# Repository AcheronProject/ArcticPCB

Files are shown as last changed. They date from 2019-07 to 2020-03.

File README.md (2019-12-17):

# Acheron 60-SM-S-STM32-MX-TH-WI (Codename "ArcticPCB")

Acheron Logo

See [this page](https://gondolindrim.github.io/AcheronDocs/arctic/intro.html) for the ArcticPCB documentation.

## Introduction

Arctic is an STM32F072-based universal 60% keyboard PCB featuring limited layouts and features. The layouts were cherry-picked by enthusiast ArcticFox and consist of only Tsangan bottom row. 

This PCB also features "relief" flex cuts aimed at improving keyboard typing feeling.

Arctic hold a very special place in my heart as it was one of the first two PCBs, together with the KeebsPCB, in the Acheron Project and effectively inaugurated it.

## Contributors

- Raphael "ArcticFox" Hochheim for helping choosing the compatible layouts
- Felipe 'MrKeebs" Coury who paid for the V1 prototypes and helped immensely by funcing my learning
- PCBWay for sponsoring the pre-revision Alpha prototypes

## Supported layouts

Click [this link](http://www.keyboard-layout-editor.com/#/gists/73be427d3e8086a9253feece2dae6974) for the KLE file for the Arctic.

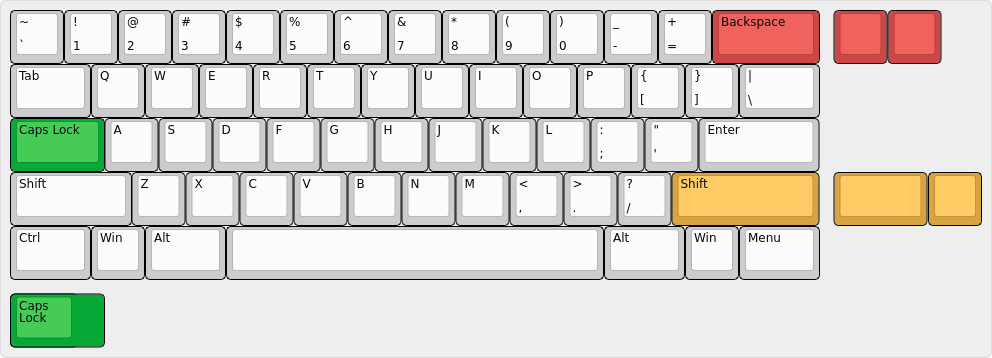
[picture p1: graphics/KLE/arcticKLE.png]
Arctic layouts


## Renders

Click at the images to zoom in.

Renders generated by the [tracespace.io](https://tracespace.io/view/) site.

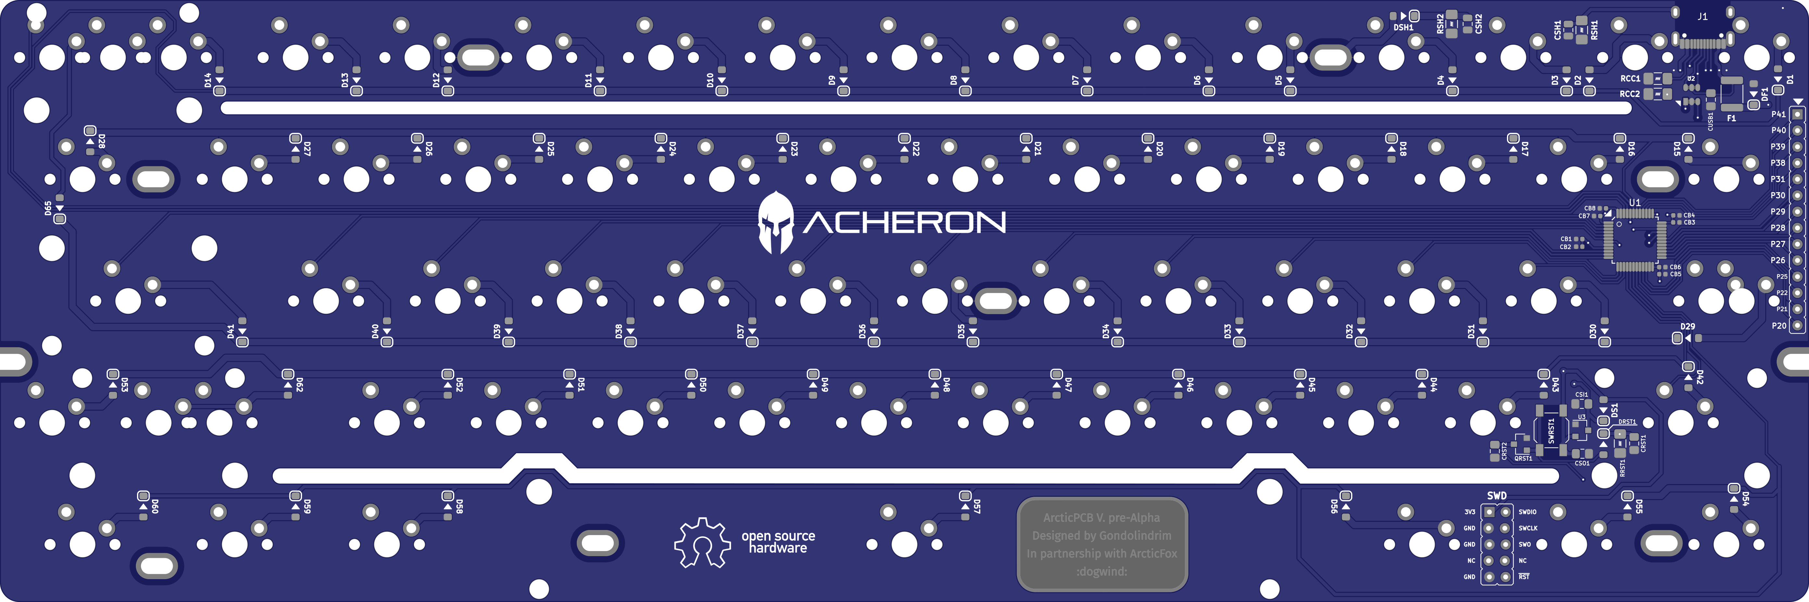
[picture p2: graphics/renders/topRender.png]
ArcticPCB Top Render


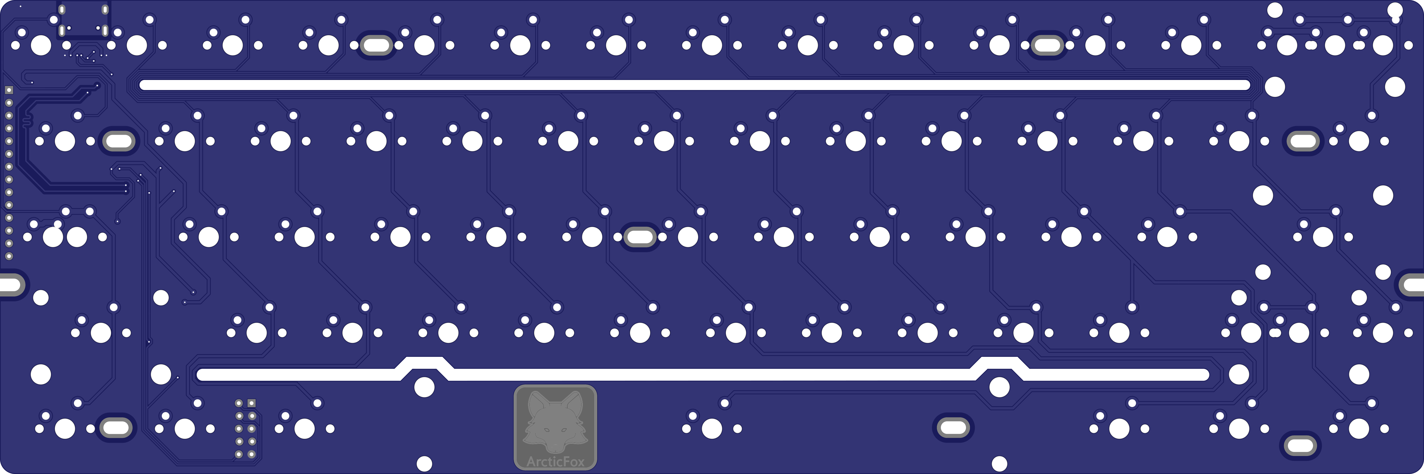
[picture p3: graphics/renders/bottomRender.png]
ArcticPCB Bottom Render


## PCBWay sponsorship

The pre-revision Alpha of the ArcticPCB was sponsored by [PCBWay](http://www.pcbway.com), a big asian PCB manufacturer that provided prototypes for the Arctic.

The review article can be found at [the AcheronDocs page](https://gondolindrim.github.io/AcheronDocs/pcbway/sponsorship.html).

## Icon

The Fox icon was based on [this design](https://www.flaticon.com/free-icon/fox_112476) and slightly modified.

## Copyright notice

This project is released under the Acheron Open-Hardware License V1.2. For the license, please refer to the LICENCE.md file.

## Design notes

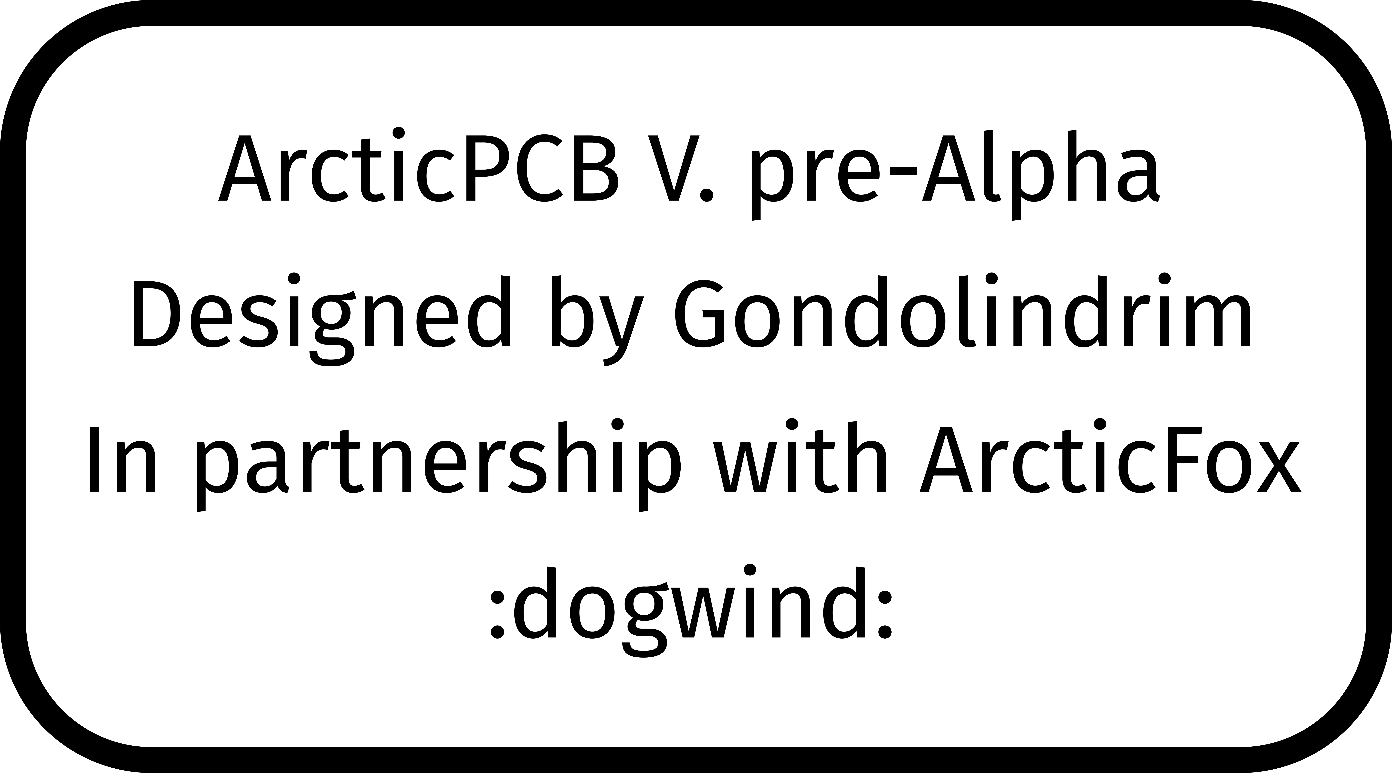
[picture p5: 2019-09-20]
graphics/arcticLabel/arcticLabel.png

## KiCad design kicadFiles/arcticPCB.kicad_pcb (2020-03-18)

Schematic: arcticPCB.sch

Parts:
CB1: 1uF; C_0402_1005Metric
CB2: 10n; C_0402_1005Metric
CB3, CB5, CB8: 100n; C_0402_1005Metric
CB4, CB6: 4.7uF; C_0402_1005Metric
CB7: 100nF; C_0402_1005Metric
CRST1: 10u; C_0805_2012Metric_Pad1.15x1.40mm_HandSolder
CRST2: 4.7n; C_0805_2012Metric_Pad1.15x1.40mm_HandSolder
CSH1, CSH2: 4.7nF; C_0805_2012Metric
CSI1: 100n; C_0805_2012Metric_Pad1.15x1.40mm_HandSolder
CSO1: 100n; C_0805_2012Metric_Pad1.15x1.40mm_HandSolder
CUSB1: 100n; C_0805_2012Metric_Pad1.15x1.40mm_HandSolder
D1, D2, D3, D4, D5, D6, D7, D8, D9, D10, D11, D12, D13, D14, D15, D16, D17, D18, D19, D20, D21, D22, D23, D24, D25, D26, D27, D28, D29, D30, D31, D32, D33, D34, D35, D36, D37, D38, D39, D40, D41, D42, D43, D44, D45, D46, D47, D48, D49, D50, D51, D52, D53, D54, D55, D56, D57, D58, D59, D60, D62, D65: 1N4148; D_SOD-123
DF1: RB060M-60TR; D_SOD-123
DRST1: 1N4148; D_SOD-123
DS1: 1N4148; D_SOD-123
DSH1: 1N4007; D_SOD-123
F1: Polyfuse; Fuse_1812_4532
H1, H6: Half Side Hole; halfSideHole
H2: Mounting Hole; MoutingHole_Oval_7mm_5.0x2.5mm
H3, H4, H5, H7, H8, H9, H10: Oval Mounting Hole; MoutingHole_Oval_7mm_5.0x2.5mm
J1: TYPE-C-31-M12_13; TYPE-C-31-M-12
J2: Conn_01x14; PinHeader_1x14_P2.54mm_Vertical
J3: Conn_ARM_JTAG_SWD_10
L1: ArcticLogo; arcticLogoFilled
L2: OSHLogo; osh-logo
L3: Acheron Logo; acheronLong
L4: ArcticLabel; arcticLabel
L5: Acheron Logo; arcticLabelMask
QRST1: DTC123J; SOT-23
RCC1, RCC2: 5.1k; R_SMD_1026
RRST1: 100k; R_SMD_1026
RSH1, RSH2: 1M; R_SMD_1026
SW1: ESC; MX100
SW2: 1; MX100
SW3: 2; MX100
SW4: 3; MX100
SW5: 4; MX100
SW6: 5; MX100
SW7: 6; MX100
SW8: 7; MX100
SW9: 8; MX100
SW10: 9; MX100
SW11: 0; MX100
SW12: -_; MX100
SW13: +=; MX100
SW14: 2U BKSP; MX200
SW15: TAB_150; MX150
SW16: Q; MX100
SW17: W; MX100
SW18: E; MX100
SW19: R; MX100
SW20: T; MX100
SW21: Y; MX100
SW22: U; MX100
SW23: I; MX100
SW24: O; MX100
SW25: P; MX100
SW26: [{; MX100
SW27: ]}; MX100
SW28: \\|_150; MX150
SW29: CAPS_175; MX175
SW30: A; MX100
SW31: S; MX100
SW32: D; MX100
SW33: F; MX100
SW34: G; MX100
SW35: H; MX100
SW36: J; MX100
SW37: K; MX100
SW38: L; MX100
SW39: :;; MX100
SW40: \"'; MX100
SW41: ENTER_225; MX225R
SW42: LSHIFT_225; MX225
SW43: Z; MX100
SW44: X; MX100
SW45: C; MX100
SW46: V; MX100
SW47: B; MX100
SW48: N; MX100
SW49: M; MX100
SW50: <,; MX100
SW51: >.; MX100
SW52: ?/; MX100
SW53: RSHIFT_275; MX275
SW54: LCTRL_150; MX150
SW55: LGUI_100; MX100
SW56: LALT_150; MX150
SW57: SPACE_7U; MX700R
SW58: RALT_150; MX150
SW59: RGUI_100; MX100
SW60: RCTRL_150; MX150
SW61: FN_100; MX100
SW62: RSHIFT_175; MX175
SW63: STEPPED_CAPS_125; MX125
SW64: 1U LBKSP; MX100
SW65: 1U RBKSP; MX100
SWRST1: SW_Push; smdPushBtn
U1: STM32F072-LQFP48; LQFP-48_7x7mm_P0.5mm
U2: USBLC6-2SC6; SOT-23-6
U3: MCP1700-3302E_SOT23; SOT-23

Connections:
3.3V: CB1.2, CB2.2, CB3.2, CB4.2, CB5.2, CB6.2, CB7.1, CB8.2, CSO1.2, DS1.2 (A), J3.1 (VTref), SWRST1.1, U1.1 (VBAT), U1.9 (VDDA), U1.24 (VDD), U1.36 (VDDIO2), U1.48 (VDD), U3.2 (VO)
5V: CSI1.2, DF1.1 (K), DS1.1 (K), F1.1, U3.3 (VI)
/SHIELD: CSH1.2, J1.S (SHIELD), RSH1.1
BOOT0: CRST1.2, DRST1.1 (K), RRST1.1, U1.44 (BOOT0)
CASE: DSH1.2 (A), H8.1
Col1: SW1.1 (Col), SW15.1 (Col), SW29.1 (Col), SW42.1 (Col), SW54.1 (Col), SW63.1 (Col), U1.18 (PB0/TIM3_CH3/ADC_IN8)
Col2: SW2.1 (Col), SW16.1 (Col), SW30.1 (Col), SW43.1 (Col), SW55.1 (Col), U1.15 (PA5/ADC_IN5/DAC_OUT2)
Col3: SW3.1 (Col), SW17.1 (Col), SW31.1 (Col), SW44.1 (Col), SW56.1 (Col), U1.14 (PA4/TIM14_CH1/ADC_IN4)
Col4: SW4.1 (Col), SW18.1 (Col), SW32.1 (Col), SW45.1 (Col), U1.13 (PA3/TIM15_CH2/ADC_IN3)
Col5: SW5.1 (Col), SW19.1 (Col), SW33.1 (Col), SW46.1 (Col), U1.12 (PA2/ADC_IN2)
Col6: SW6.1 (Col), SW20.1 (Col), SW34.1 (Col), SW47.1 (Col), U1.11 (PA1/ADC_IN1)
Col7: SW7.1 (Col), SW21.1 (Col), SW35.1 (Col), SW48.1 (Col), SW57.1 (Col), U1.10 (PA0/ADC_IN0)
Col8: SW8.1 (Col), SW22.1 (Col), SW36.1 (Col), SW49.1 (Col), U1.6 (PF1/OSC_OUT)
Col9: SW9.1 (Col), SW23.1 (Col), SW37.1 (Col), SW50.1 (Col), U1.5 (PF0/OSC_IN)
Col10: SW10.1 (Col), SW24.1 (Col), SW38.1 (Col), SW51.1 (Col), SW58.1 (Col), U1.4 (PC15/OSC32_OUT)
Col11: SW11.1 (Col), SW25.1 (Col), SW39.1 (Col), SW52.1 (Col), SW59.1 (Col), U1.3 (PC14/OSC32_IN)
Col12: SW12.1 (Col), SW26.1 (Col), SW40.1 (Col), SW53.1 (Col), SW60.1 (Col), SW62.1 (Col), U1.2 (PC13)
Col13: SW13.1 (Col), SW27.1 (Col), SW41.1 (Col), SW61.1 (Col), U1.46 (SPI2_NSS/I2S2_WS/I2C1_SDA/TIM17_CH1/PB9)
Col14: SW14.1 (Col), SW28.1 (Col), SW64.1 (Col), SW65.1 (Col), U1.45 (I2C1_SCL/TIM16_CH1/PB8)
D+: U1.33 (USB_DP/PA12), U2.3 (IO2)
D-: U1.32 (USB_DM/TIM1_CH4/PA11), U2.1 (IO1)
DBus+: J1.A6 (D+), J1.B6 (D+), U2.4 (IO2)
DBus-: J1.A7 (D-), J1.B7 (D-), U2.6 (IO1)
Extra1: J2.1, U1.41 (SPI1_MOSI/I2S1_SD/TIM3_CH2/PB5)
Extra2: J2.2, U1.40 (SPI1_MISO/I2S1_MCK/TIM3_CH1/PB4)
Extra3: J2.3, U1.39 (SPI1_SCK/I2S1_CK/TIM2_CH2/PB3)
Extra4: J2.4, U1.38 (PA2)
Extra5: J2.5, U1.31 (TIM1_CH3/PA10)
Extra6: J2.6, U1.30 (TIM1_CH2/PA9)
Extra7: J2.7, U1.29 (TIM1_CH1/PA8)
Extra8: J2.8, U1.28 (SPI2_MOSI/I2S2_SD/PB15)
Extra9: J2.9, U1.27 (PB14/SPI2_MISO/I2S2_MCK/I2C2_SDA/TIM15_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)
Extra10: J2.10, U1.26 (SPI2_SCK/I2S2_CK/I2C2_SCL/PB13)
Extra11: J2.11, U1.25 (PB12)
Extra12: J2.12, U1.22 (PB11/TIM2_CH4/I2C2_SDA)
Extra13: J2.13, U1.21 (PB10/SPI2_SCK/I2C2_SCL/TIM2_CH3)
Extra14: J2.14, U1.20 (PB2)
GND: CB1.1, CB2.1, CB3.1, CB4.1, CB5.1, CB6.1, CB7.2, CB8.1, CRST1.1, CRST2.2, CSH1.1, CSH2.1, CSI1.1, CSO1.1, CUSB1.1, DF1.2 (A), J1.A1 (GND), J1.B1 (GND), J3.3 (GND), J3.5 (GND), J3.9 (GNDDetect), QRST1.2 (E), RCC1.1, RCC2.1, RRST1.2, RSH1.2, RSH2.2, U1.8 (VSSA), U1.23 (VSS), U1.35 (VSS), U1.47 (VSS), U2.2 (GND), U3.1 (GND)
NRST: CRST2.1, J3.10 (~RESET~), QRST1.3 (C), U1.7 (NRST)
unnamed: CSH2.2, DSH1.1 (K), RSH2.1
unnamed: D1.2 (A), SW1.2 (Row)
unnamed: D2.2 (A), SW2.2 (Row)
unnamed: D3.2 (A), SW3.2 (Row)
unnamed: D4.2 (A), SW4.2 (Row)
unnamed: D5.2 (A), SW5.2 (Row)
unnamed: D6.2 (A), SW6.2 (Row)
unnamed: D7.2 (A), SW7.2 (Row)
unnamed: D8.2 (A), SW8.2 (Row)
unnamed: D9.2 (A), SW9.2 (Row)
unnamed: D10.2 (A), SW10.2 (Row)
unnamed: D11.2 (A), SW11.2 (Row)
unnamed: D12.2 (A), SW12.2 (Row)
unnamed: D13.2 (A), SW13.2 (Row)
unnamed: D14.2 (A), SW14.2 (Row), SW64.2 (Row)
unnamed: D15.2 (A), SW15.2 (Row)
unnamed: D16.2 (A), SW16.2 (Row)
unnamed: D17.2 (A), SW17.2 (Row)
unnamed: D18.2 (A), SW18.2 (Row)
unnamed: D19.2 (A), SW19.2 (Row)
unnamed: D20.2 (A), SW20.2 (Row)
unnamed: D21.2 (A), SW21.2 (Row)
unnamed: D22.2 (A), SW22.2 (Row)
unnamed: D23.2 (A), SW23.2 (Row)
unnamed: D24.2 (A), SW24.2 (Row)
unnamed: D25.2 (A), SW25.2 (Row)
unnamed: D26.2 (A), SW26.2 (Row)
unnamed: D27.2 (A), SW27.2 (Row)
unnamed: D28.2 (A), SW28.2 (Row)
unnamed: D29.2 (A), SW29.2 (Row), SW63.2 (Row)
unnamed: D30.2 (A), SW30.2 (Row)
unnamed: D31.2 (A), SW31.2 (Row)
unnamed: D32.2 (A), SW32.2 (Row)
unnamed: D33.2 (A), SW33.2 (Row)
unnamed: D34.2 (A), SW34.2 (Row)
unnamed: D35.2 (A), SW35.2 (Row)
unnamed: D36.2 (A), SW36.2 (Row)
unnamed: D37.2 (A), SW37.2 (Row)
unnamed: D38.2 (A), SW38.2 (Row)
unnamed: D39.2 (A), SW39.2 (Row)
unnamed: D40.2 (A), SW40.2 (Row)
unnamed: D41.2 (A), SW41.2 (Row)
unnamed: D42.2 (A), SW42.2 (Row)
unnamed: D43.2 (A), SW43.2 (Row)
unnamed: D44.2 (A), SW44.2 (Row)
unnamed: D45.2 (A), SW45.2 (Row)
unnamed: D46.2 (A), SW46.2 (Row)
unnamed: D47.2 (A), SW47.2 (Row)
unnamed: D48.2 (A), SW48.2 (Row)
unnamed: D49.2 (A), SW49.2 (Row)
unnamed: D50.2 (A), SW50.2 (Row)
unnamed: D51.2 (A), SW51.2 (Row)
unnamed: D52.2 (A), SW52.2 (Row)
unnamed: D53.2 (A), SW61.2 (Row)
unnamed: D54.2 (A), SW54.2 (Row)
unnamed: D55.2 (A), SW55.2 (Row)
unnamed: D56.2 (A), SW56.2 (Row)
unnamed: D57.2 (A), SW57.2 (Row)
unnamed: D58.2 (A), SW58.2 (Row)
unnamed: D59.2 (A), SW59.2 (Row)
unnamed: D60.2 (A), SW60.2 (Row)
unnamed: D62.2 (A), SW53.2 (Row), SW62.2 (Row)
unnamed: D65.2 (A), SW65.2 (Row)
unnamed: DRST1.2 (A), QRST1.1 (B), SWRST1.2
unnamed: J1.A5 (CC1), RCC2.2
unnamed: J1.B5 (CC2), RCC1.2
Row1: D1.1 (K), D2.1 (K), D3.1 (K), D4.1 (K), D5.1 (K), D6.1 (K), D7.1 (K), D8.1 (K), D9.1 (K), D10.1 (K), D11.1 (K), D12.1 (K), D13.1 (K), D14.1 (K), U1.43 (2C1_SDA/PB7)
Row2: D15.1 (K), D16.1 (K), D17.1 (K), D18.1 (K), D19.1 (K), D20.1 (K), D21.1 (K), D22.1 (K), D23.1 (K), D24.1 (K), D25.1 (K), D26.1 (K), D27.1 (K), D28.1 (K), U1.42 (I2C1_SCL/PB6)
Row3: D29.1 (K), D30.1 (K), D31.1 (K), D32.1 (K), D33.1 (K), D34.1 (K), D35.1 (K), D36.1 (K), D37.1 (K), D38.1 (K), D39.1 (K), D40.1 (K), D41.1 (K), D65.1 (K), U1.16 (PA6/ADC_IN6/TIM3_CH1/TIM16_CH1)
Row4: D42.1 (K), D43.1 (K), D44.1 (K), D45.1 (K), D46.1 (K), D47.1 (K), D48.1 (K), D49.1 (K), D50.1 (K), D51.1 (K), D52.1 (K), D53.1 (K), D62.1 (K), U1.17 (PA7/TIM3_CH2/TIM14_CH1/ADC_IN7)
Row5: D54.1 (K), D55.1 (K), D56.1 (K), D57.1 (K), D58.1 (K), D59.1 (K), D60.1 (K), U1.19 (PB1/TIM3_CH4/TIM14_CH1/ADC_IN9)
SWCLK: J3.4 (SWDCLK/TCK), U1.37 (SWCLK/PA14)
SWDIO: J3.2 (SWDIO/TMS), U1.34 (SWDIO/PA13)
VBUS: CUSB1.2, F1.2, J1.A4 (VBUS), J1.B4 (VBUS), U2.5 (VBUS)

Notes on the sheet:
REFERENCES
[1] STM32F072x8 / STM32F072xB datasheet
https://www.st.com/resource/en/datasheet/stm32f072rb.pdf
[2] AN4080 Application note
https://www.st.com/content/ccc/resource/technical/document/application_note/c9/19/d7/b8/6b/0e/4c/d3/DM00051986.pdf/files/DM00051986.pdf/jcr:content/translations/en.D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
Switch matrix
Logos and flags
Mounting holes
Shield
USB Connector
USD ESD
Power supply and protection circuit
Serial programming
Hard reset circuit
Case ESD
Extra pins
CBx are the bypass capacitors. Their value is specified in reference [2].
MCU

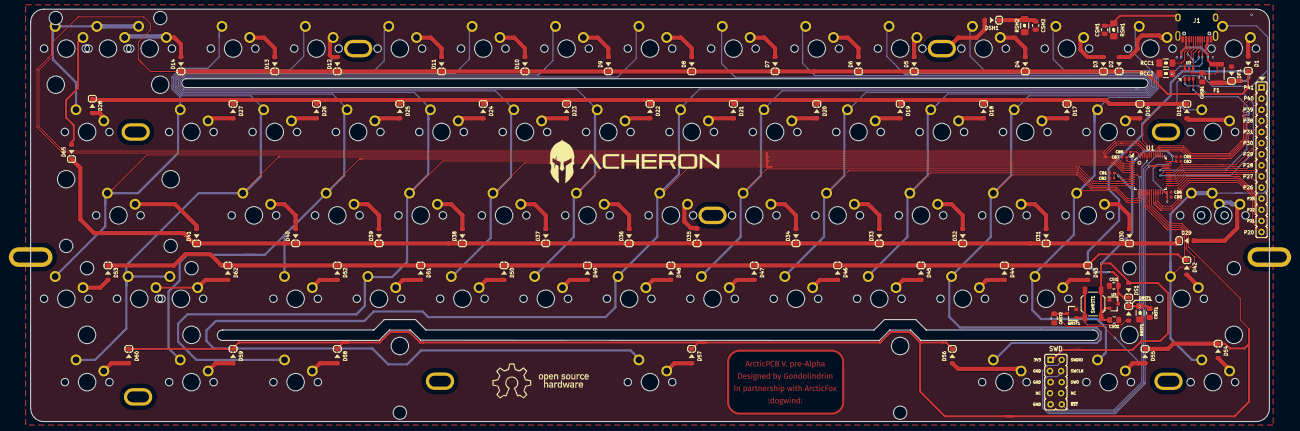
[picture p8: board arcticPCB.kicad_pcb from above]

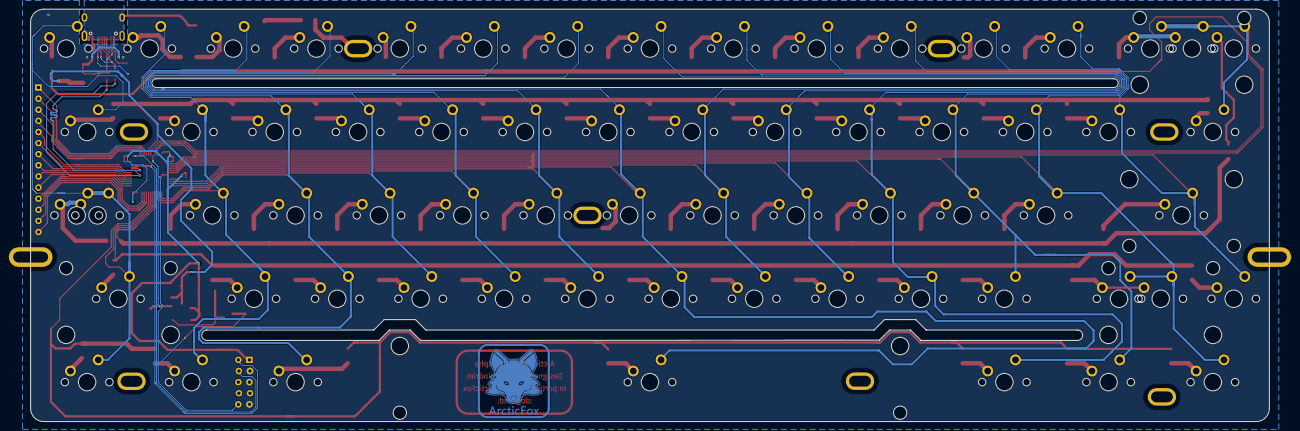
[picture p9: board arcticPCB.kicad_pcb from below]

Board: 2 copper layers, 283.0 x 94.2 mm, 175 parts (7 on the bottom side), 113 nets.

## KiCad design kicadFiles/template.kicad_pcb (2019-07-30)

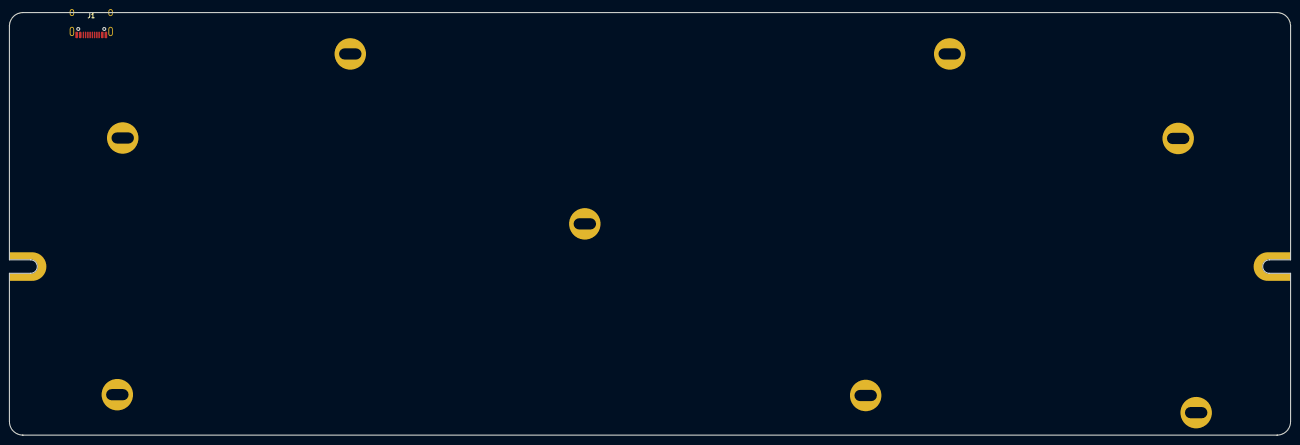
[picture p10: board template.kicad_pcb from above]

Board: 2 copper layers, 285.0 x 94.0 mm, 11 parts (0 on the bottom side), 5 nets, no tracks yet.

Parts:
H1, H6: Half Side Hole; halfSideHole
H2: Mounting Hole; MoutingHole_Oval_7mm_5.0x2.5mm
H3, H4, H5, H7, H8, H9, H10: Oval Mounting Hole; MoutingHole_Oval_7mm_5.0x2.5mm
J1: TYPE-C-31-M12_13; TYPE-C-31-M-12

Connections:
DBus+: J1.A7, J1.B7
DBus-: J1.A6, J1.B6
GND: J1.A1, J1.B1
unnamed: J1.A5, J1.B5
VBUS: J1.A4, J1.B4

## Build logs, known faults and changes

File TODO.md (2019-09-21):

# ArcticPCB TODO list (Alpha release roadmap)

- [] Compile the Bill of Materials and quote components on LCSC site.

- [] Compile gerbers and make the Alpha release page on GitHub.

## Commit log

2018-12-21 Added pertinent PCB design articles
2019-02-10 Used SharkPCB schematic as canvas
    [arctic.sch, gh60.kicad_pcb, gh60.sch]
2019-03-15 [Base] Added dimensions and mounting holes
    [60_Keyboard_Case.stl, arctic.sch, arcticPCB.kicad_pcb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]
2019-07-30 [Update] Places some switches
    [arcticPCB.kicad_pcb, arcticPCB.sch, template.kicad_pcb]
2019-07-30 [Update] Finished placing switches, placed logo
    [arcticPCB.kicad_pcb, arcticPCB.sch]
2019-07-31 [Update] Added 1mm clearance to mounting holes and added ground planes
    [arcticPCB.kicad_pcb]
2019-07-31 [Update,Feature] Added flex cuts, routed and placed most components
    [arcticPCB.kicad_pcb, arcticPCB.sch]
2019-08-01 [Update] Finished routing
    [arcticPCB.kicad_pcb, arcticPCB.sch]
2019-08-01 [Update] Added mounting holes ESD protection
    [arcticPCB.kicad_pcb, arcticPCB.sch]
2019-08-20 Added 3D models and Blender file
    - STEP and VMRL models of the current PCB were added to the 3D_Models folder.
    - Using the VMRL a Blender file was added to the blender folder. This file contains only some renaming and a camera configuration for the scene, adding materials and appearances is still needed.
2019-09-02 Added RCC2
    - The PCB used a single pulldown resistor for both CC1 and CC2 pins of the USB connector, which is not the right way to do it. This has been fixed and now each CC pin has a single resistor.
    [arcticPCB.kicad_pcb]
2019-09-18 Add extra pins, organize schematic, add renders
    - There were two pins in the PCB that were left unused and un-exposed to use. Now those two pins are broken out so they can be used. To execute this, some cols and rows had to have their pins reallocated.
    - Schematic is better organized;
    - Added KLE and PCB renders at the REAME file.
    [60_Keyboard_Case.stl, arcticPCB.kicad_pcb, arcticPCB.sch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]
2019-09-19 Update AcheronLibrary submodule
    [arcticPCB-B_Cu.gbr, arcticPCB-B_Fab.gbr, arcticPCB-B_Mask.gbr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]
2019-09-20 Optimize routing, move SWD pins
    [arcticPCB.kicad_pcb, arcticPCB.sch]
2019-09-20 Reorganize graphics, optimize routing
    - The ./graphics folder was reorganized
    - Some traces, specially the ones leading to SWD pins, were re-done for
    efficiency and optimization
    [arcticPCB.kicad_pcb, arcticPCB.sch]
2019-09-20 Update Library, improve footprints and label
    - The label was previously written "release Alpha" which is not the case (this is still version pre-Alpha);
    - New MX_SolderMask witch footprints from the AcheronLibrary
    - The extra pins were allocated into three symbols (J2, J3 and J4). These were grouped under the same J2, having 14 pins and an improved footprint;
    - Optimized routing near the MCU area;
    - Added more clearance to the D+/D- differential pair to make sure it is free from interference;
    [arcticPCB.kicad_pcb, arcticPCB.sch]
2019-09-21 Add new pin header footprints
    - The AcheronLibrary pin header footprints were updated, and a SWD JTAG
    footprint was added (see AcheronLibrary commit 280b825).
    - Following this, the pin header footprints on Arctic were redone and
    the JTAG footprint was added.
    [arcticPCB.kicad_pcb, arcticPCB.sch]
2019-09-21 Improved diff. pair pad clearances
    - The differential pair D-/D+ has a 20thou clearance, which was used by
    KiCad for the pads on USBLC6 (U2) and the microprocessor (U1), making
    the filled zones around those pads not so good. The net clearance of
    20thou remains, although the pads now have a normal clearance of 6 thou.
    [arcticPCB.kicad_pcb, arcticPCB.sch]
2019-09-21 Continue improvements from last commit.
    [arcticPCB.kicad_pcb]
2019-09-22 Update: fixed naming of top row
    [arcticPCB-B_Cu.gbr, arcticPCB-B_Fab.gbr, arcticPCB-B_Mask.gbr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]
2019-09-22 Fix: problem of RALT key placement
    [arcticPCB.kicad_pcb]
2019-09-23 Fix: problem with GND pour and Col7 routing
    [arcticPCB.kicad_pcb]
2020-01-18 Fiz RShift / Enter stab collision issue
    - The RShift and Enter stabs were positioned in a way that they would collide. The Enter stab was rotated to avoid this.
    [arcticPCB.kicad_pcb, arcticPCB.sch]
2020-03-18 Solve pre-Alpha prototype issues
    This commit solves the issues found in the pre-Alpha prototypes:
    - In the USB connector, the D+ and D- pads were switched; this has been fixed and the differential pair routing was improved;
    - The split Right Shift keyswitches SW62 for the 1.75U RShift and 1U SW61 for the Fn were in the wrong orientation: the Fn key SW61 was on the left and SW62 was on the left. They were swapped for the right orientation now;
    - Also, to make firmware definitions easier, the 1.75U RShift key and 2.75U RShift key are now at the same position, whereas in pre-Alpha SW62 for the 1.75RShift was at the same position with SW61 for the 1U Fn, which made firmware need two definitions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
    [arcticPCB.kicad_pcb, arcticPCB.sch]
2020-03-18 Refresh renders for rev Alpha
    [arcticPCB.kicad_pcb]
